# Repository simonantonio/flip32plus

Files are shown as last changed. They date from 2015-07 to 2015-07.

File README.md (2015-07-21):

# twist32+

This should be pin compatible with the naze32/flip32+ but will require modified firmware to drive the MPU9120

Newly laid out PCB based on the MPU9250 (accelerometer, gyroscope, magnetometer)
MS5611-01BA - Barometer 

Designed to fit the standard 36mm footprint of other flight controllers.

Power via ESC 1.

Makes use of JST SH connectors to take up less board space and make wiring tidier

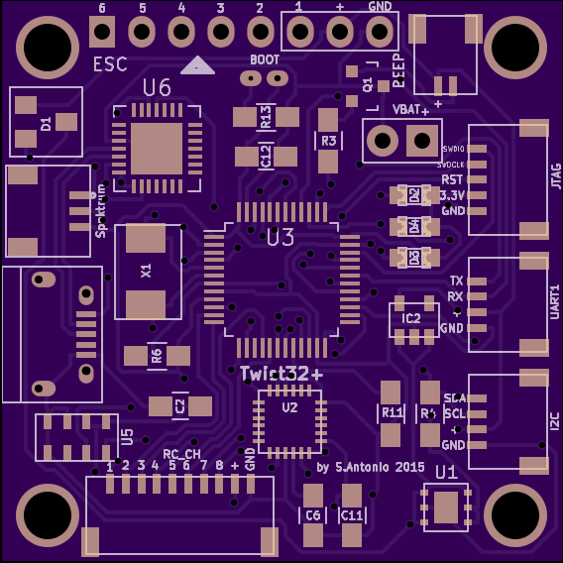
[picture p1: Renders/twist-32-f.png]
Twist32+ Front

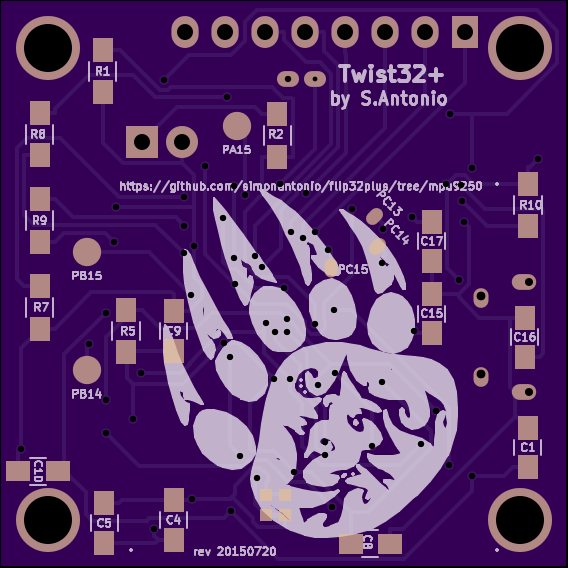
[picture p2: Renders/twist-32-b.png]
Twist32+ Back


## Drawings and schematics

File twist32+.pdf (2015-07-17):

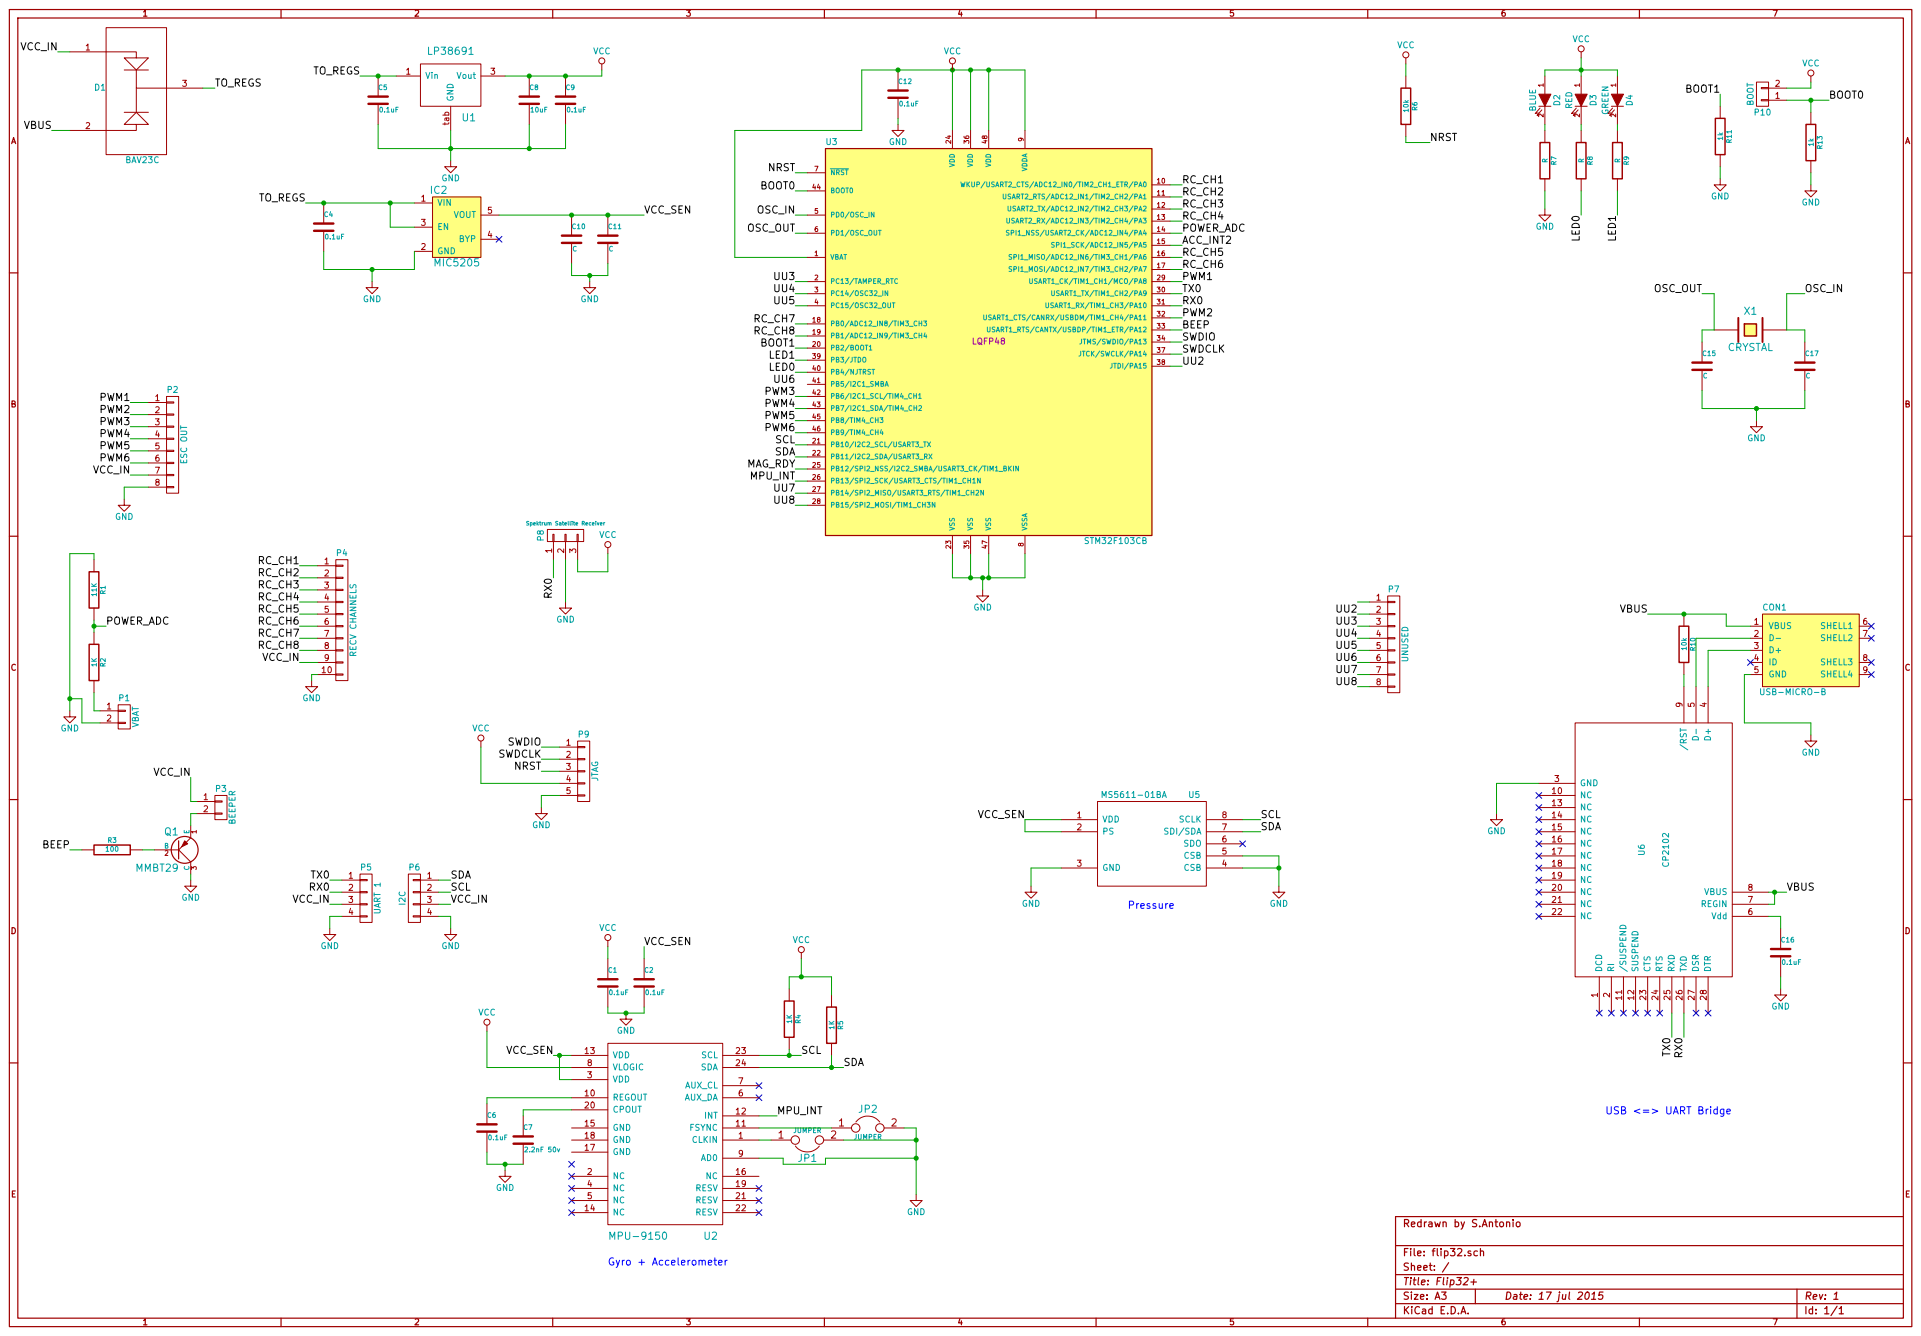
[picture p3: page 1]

9 WKUP/USART2_CTS/ADC12_IN0/TIM2_CH1_ETR/PA0 10 PB2/BOOT1 20 USART1_TX/TIM1_CH2/PA9 30 PB4/NJTRST 40 USART2_RTS/ADC12_IN1/TIM2_CH2/PA1 11 PB10/I2C2_SCL/USART3_TX 21 USART1_RX/TIM1_CH3/PA10 31 PB5/I2C1_SMBA 41 USART2_TX/ADC12_IN2/TIM2_CH3/PA2 12 PB11/I2C2_SDA/USART3_RX 22 USART1_CTS/CANRX/USBDM/TIM1_CH4/PA11 32 PB6/I2C1_SCL/TIM4_CH1 42 USART2_RX/ADC12_IN3/TIM2_CH4/PA3 13 VSS 23 USART1_RTS/CANTX/USBDP/TIM1_ETR/PA12 33 PB7/I2C1_SDA/TIM4_CH2 43 SPI1_NSS/USART2_CK/ADC12_IN4/PA4 14 VDD 24

Spektrum Satellite Receiver RX0 GND

9 NC 10 NC 20 /SUSPEND 11 NC 21 SUSPEND 12 NC 22 NC 13 CTS 23 NC 14 RTS 24 NC 15 RXD 25 NC 16 TXD 26 NC 17 DSR 27 NC 18 DTR 28 NC 19 U6 CP2102 10k R10

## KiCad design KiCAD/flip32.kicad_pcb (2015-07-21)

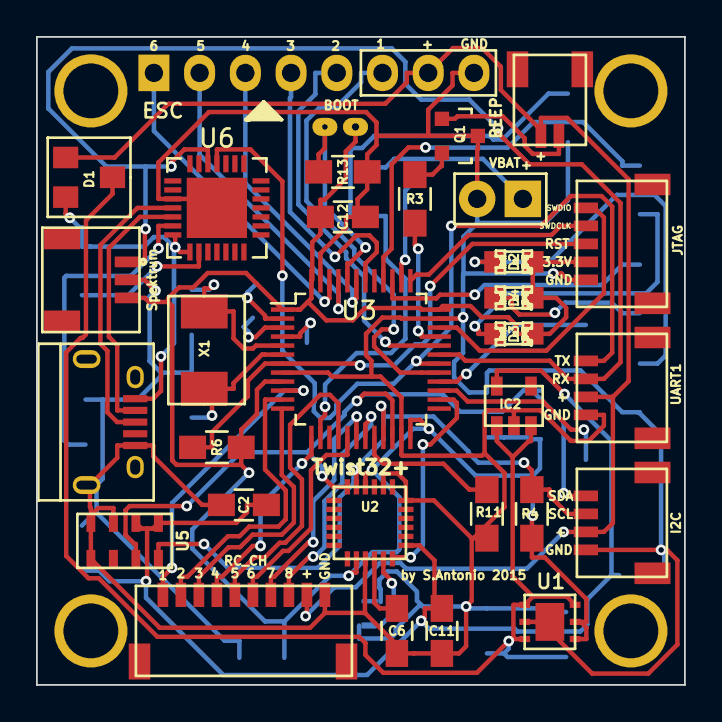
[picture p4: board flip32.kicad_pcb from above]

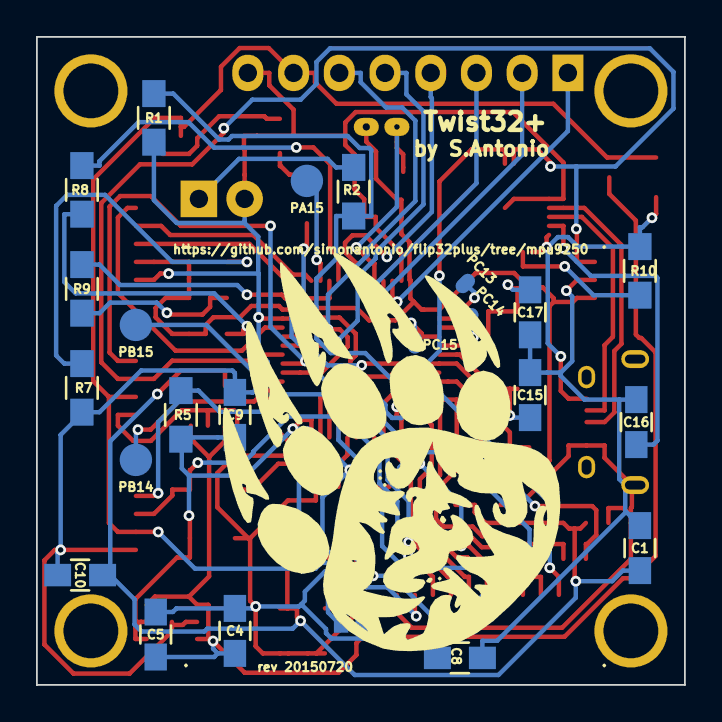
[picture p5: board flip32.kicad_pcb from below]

Board: 2 copper layers, 36.0 x 36.0 mm, 59 parts (24 on the bottom side), 54 nets.

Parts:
BEEP: BEEPER; Pin_Header_Straight_1x02
BOOT: BOOT; Pin_Header_Straight_1x02
C1, C2, C4, C5, C6, C9, C12, C16: 0.1uF; C_0805_HandSoldering
C8: 10uF; C_0805_HandSoldering
C10, C11, C15, C17: C; C_0805_HandSoldering
CON1: USB; USB_Micro-B
D1: BAV23C; GS3
D2: B; LED-0805
D3: R; LED-0805
D4: G; LED-0805
ESC: ESC OUT; Pin_Header_Straight_1x08
FSYNC-MPU: MPU-JMP; NetTie-I_Connected
I2C: I2C; Pin_Header_Straight_1x04
IC2: MIC5205; SOT-23-5
JP1: MPU-JMP; NetTie-I_Connected
JTAG: JTAG; Pin_Header_Straight_1x05
MNT1, MNT2, MNT3, MNT4: 1pin
PA15: TP; 1pin
PB14, PB15: TP; 1pin
PC13, PC14, PC15: UU5; 1pin
Q1: MMBT29; SOT-23
R1: 11K; R_0805_HandSoldering
R2, R4, R5: 1K; R_0805_HandSoldering
R3: 100; R_0805_HandSoldering
R6, R10: 10k; R_0805_HandSoldering
R7, R8, R9: R; R_0805_HandSoldering
R11, R13: 1k; R_0805_HandSoldering
RC_CH: RECV CHANNELS; Pin_Header_Straight_1x10
Spektrum: Spektrum Satellite Receiver; Pin_Header_Straight_1x03
U1: LP38691; sc70-5
U2: MPU-9250; QFN-24-1EP_3x3mm_Pitch0.4mm
U3: STM32F103CB; LQFP-48_7x7mm_Pitch0.5mm
U5: MS5611-01BA; SOIC-8_3.9x4.9mm_Pitch1.27mm
U6: CP2102; QFN-28-1EP_5x5mm_Pitch0.5mm
UART1: UART 1; Pin_Header_Straight_1x04
VBAT: VBAT; Socket_Strip_Straight_1x02
X1: 8MHZ; Q_49U3HMS

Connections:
/BOOT0: BOOT.1, R13.1, U3.44
/BOOT1: R11.1, U3.20
/LED0: R8.2, U3.40
/LED1: R9.2, U3.39
/MPU_INT: U2.12, U3.26
/NRST: JTAG.3, R6.2, U3.7
/OSC_IN: C17.1, U3.5, X1.2
/OSC_OUT: C15.1, U3.6, X1.1
/POWER_ADC: R1.2, R2.1, U3.14
/PWM1: ESC.6, U3.29
/PWM2: ESC.5, U3.32
/PWM3: ESC.4, U3.42
/PWM4: ESC.3, U3.43
/PWM5: ESC.2, U3.45
/PWM6: ESC.1, U3.46
/RC_CH1: RC_CH.1, U3.10
/RC_CH2: RC_CH.2, U3.11
/RC_CH3: RC_CH.3, U3.12
/RC_CH4: RC_CH.4, U3.13
/RC_CH5: RC_CH.5, U3.16
/RC_CH6: RC_CH.6, U3.17
/RC_CH7: RC_CH.7, U3.18
/RC_CH8: RC_CH.8, U3.19
/RX0: Spektrum.1, U3.31, U6.26, UART1.2
/SCL: I2C.2, R4.2, U2.23, U3.21, U5.8
/SDA: I2C.1, R5.2, U2.24, U3.22, U5.7
/SWDCLK: JTAG.2, U3.37
/SWDIO: JTAG.1, U3.34
/TO_REGS: C4.1, C5.1, D1.3, IC2.1, IC2.3, U1.1, U1.3, U1.6
/TX0: U3.30, U6.25, UART1.1
/UU1: R3.1, U3.33
/UU2: PA15.1, U3.38
/UU3: PC13.1, U3.2
/UU4: PC14.1, U3.3
/UU5: PC15.1, U3.4
/UU7: PB14.1, U3.27
/UU8: PB15.1, U3.28
/VBUS: CON1.1, D1.2, R10.1, U6.7, U6.8
/VCC_IN: BEEP.1, D1.1, ESC.7, I2C.3, RC_CH.9, UART1.3
/VCC_SEN: C1.1, C2.1, C10.1, C11.1, IC2.5, U2.13, U5.1, U5.2
GND: C1.2, C2.2, C4.2, C5.2, C6.2, C8.2, C9.2, C10.2, C11.2, C12.2, C15.2, C16.2, C17.2, CON1.5, CON1.6, ESC.8, FSYNC-MPU.2, I2C.4, IC2.2, JP1.2, JTAG.5, Q1.3, R1.1, R7.2, R11.2, R13.2, RC_CH.10, Spektrum.2, U1.2, U1.7, U2.9, U2.18, U2.20, U3.8, U3.23, U3.35, U3.47, U5.3, U5.4, U5.5, U6.3, U6.29, UART1.4, VBAT.2
unnamed: R10.2, U6.9
unnamed: CON1.2, U6.5
unnamed: CON1.3, U6.4
unnamed: C6.1, U2.10
unnamed: FSYNC-MPU.1, U2.11
unnamed: C16.1, U6.6
unnamed: D3.2, R8.1
unnamed: D4.2, R9.1
unnamed: D2.2, R7.1
unnamed: Q1.2, R3.2
unnamed: BEEP.2, Q1.1
unnamed: R2.2, VBAT.1
VCC: BOOT.2, C8.1, C9.1, C12.1, D2.1, D3.1, D4.1, JTAG.4, R4.1, R5.1, R6.1, Spektrum.3, U1.4, U1.5, U2.8, U2.22, U3.1, U3.9, U3.24, U3.36, U3.48

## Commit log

2015-07-14 My version of the schematic. Hopefully more readable than the crappy jpg version found online
2015-07-14 initial version of the flip32+ schematic and netlist in KiCAD
    Note that the footprints are not the same as the original board, there may also be slightly different part numbers, and a few more by pass caps.
    [flip32.sch]
2015-07-16 Removed unused accelormeter (MMA8452Q)
    [flip32.sch]
2015-07-17 Finished pcb layout for MPU9150
    [$flip32.sch, flip32.dsn, flip32.kicad_pcb]
2015-07-17 fixed some missing labels
    [flip32.kicad_pcb]
2015-07-17 updated schematic pdf
2015-07-20 swapped from old mpu9150 to newer mpu9250
    [$flip32.sch, flip32.dsn, flip32.kicad_pcb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]
2015-07-20 redoing layout of traces for updated pinout of mpu9250
    [flip32.dsn, flip32.kicad_pcb]
2015-07-20 pcb completed
    [$flip32.sch, flip32.kicad_pcb]
2015-07-20 new gerbers for mpu9250
    [flip32-B_Cu.gbl, flip32-B_Mask.gbs, flip32-B_SilkS.gbo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]
2015-07-21 optimize layout, reduced track length, reduced via count
    [flip32-B_Cu.gbl, flip32-B_Mask.gbs, flip32-B_SilkS.gbo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]
2015-07-21 add gerbers zip
2015-07-21 add renders of board
    [$flip32.sch, flip32.sch]
